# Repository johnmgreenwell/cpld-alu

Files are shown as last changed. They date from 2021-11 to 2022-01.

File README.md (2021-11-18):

# CPLD ALU Test Project

MAX II CPLD custom ALU with microcontroller interface

## Overview

This test project comprises a custom 8-bit Arithmetic Logic Unit (ALU) written in Verilog and uploaded to an Altera [MAX II EPM240T100C5](https://www.digikey.com/en/products/detail/intel/EPM240T100C5/703853) Complex Programmable Logic Device (CPLD), which is interfaced with a PJRC [Teensy 4.0](https://www.pjrc.com/store/teensy40.html) microcontroller for data exchange and display.

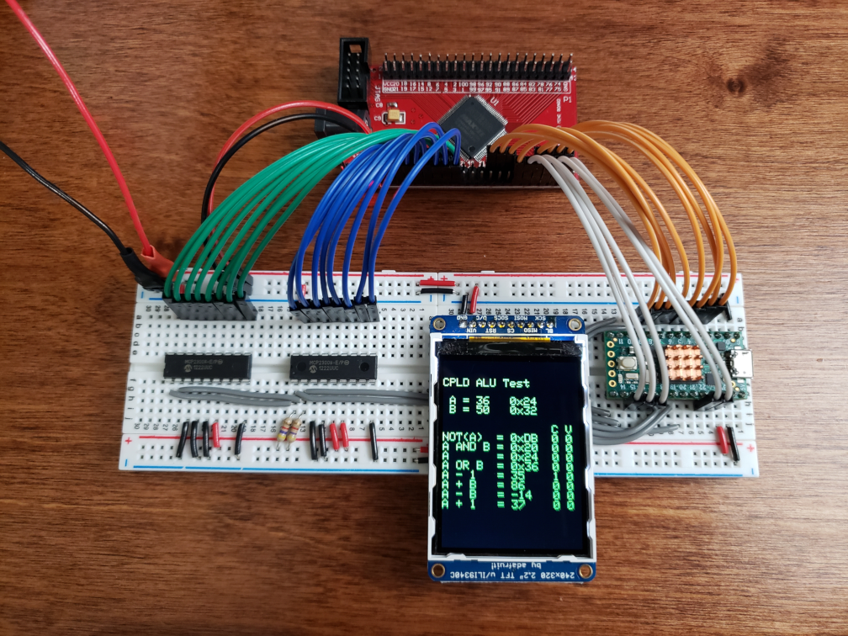
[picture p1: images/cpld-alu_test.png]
Example Breadboard


Inputs A and B are delivered to the ALU from the microcontroller via two Microchip [MCP23008 IO Expander](https://www.digikey.com/en/products/detail/microchip-technology/MCP23008-E-P/735951) chips, while the result F and the ALU control lines are connected to the microcontroller directly. Each of the eight control states are cycled for arbitrary inputs A and B, and the results are displayed using an Adafruit [ILI9340 TFT-LCD](https://www.adafruit.com/product/1480) board.

## Usage

The custom ALU may be instantiated as a single generic unit whose bus widths are determined soley by its assigned parameter N, using the Verilog design file [alun.v](src/cpld/alun.v) (and its dependencies). The design format is fully structural, in order to implement the ALU as a very specific succession of logic gates.

```v
module cpld_alu_top
#(
    parameter N = 8
)
(
    input  m,
    input  [1:0] s,
    input  [N-1:0] a,
    input  [N-1:0] b,
    output [N-1:0] f,
    output v,
    output c
);

alun #(N) uut (
    .m(m),
    .s(s),
    .a(a),
    .b(b),
    .f(f),
    .v(v),
    .c(c)
);

endmodule
```

The core test cycle performed by the microcontroller consists of assigning A, B, and the control lines as outputs to the ALU, and querying the results F, Co, and Ov as inputs. Two custom libraries, [mcp23x08.h](src/controller/src/mcp23x08.h) and [virtualport.h](src/controller/src/virtualport.h) are used to handle this IO, and the LCD is operated using the [Adafruit_ILI9340](https://github.com/adafruit/Adafruit_ILI9340) external library. All eight control states are tested in this cycle for any given inputs A and B.

```cpp
// Issue each control command 0-7 and print results
for (int8_t i=0; i<8; i++) {
    control.write(i);
    lcd.print(op_str[i]);
    if (i < 4) // Print in hex for logical
        lcd.printf(" = 0x%0*X  ", 2, port_F.read());
    else       // Print in dec for arithmetic
        lcd.printf(" = %-*i  ", 4, (int8_t)port_F.read());
    lcd.printf("%i %i\n",digitalRead(CO_PIN), digitalRead(OV_PIN));
}
```

## Schematic

The block diagram schematic for the ALU is included as drawn in Cadence Virtuoso software.

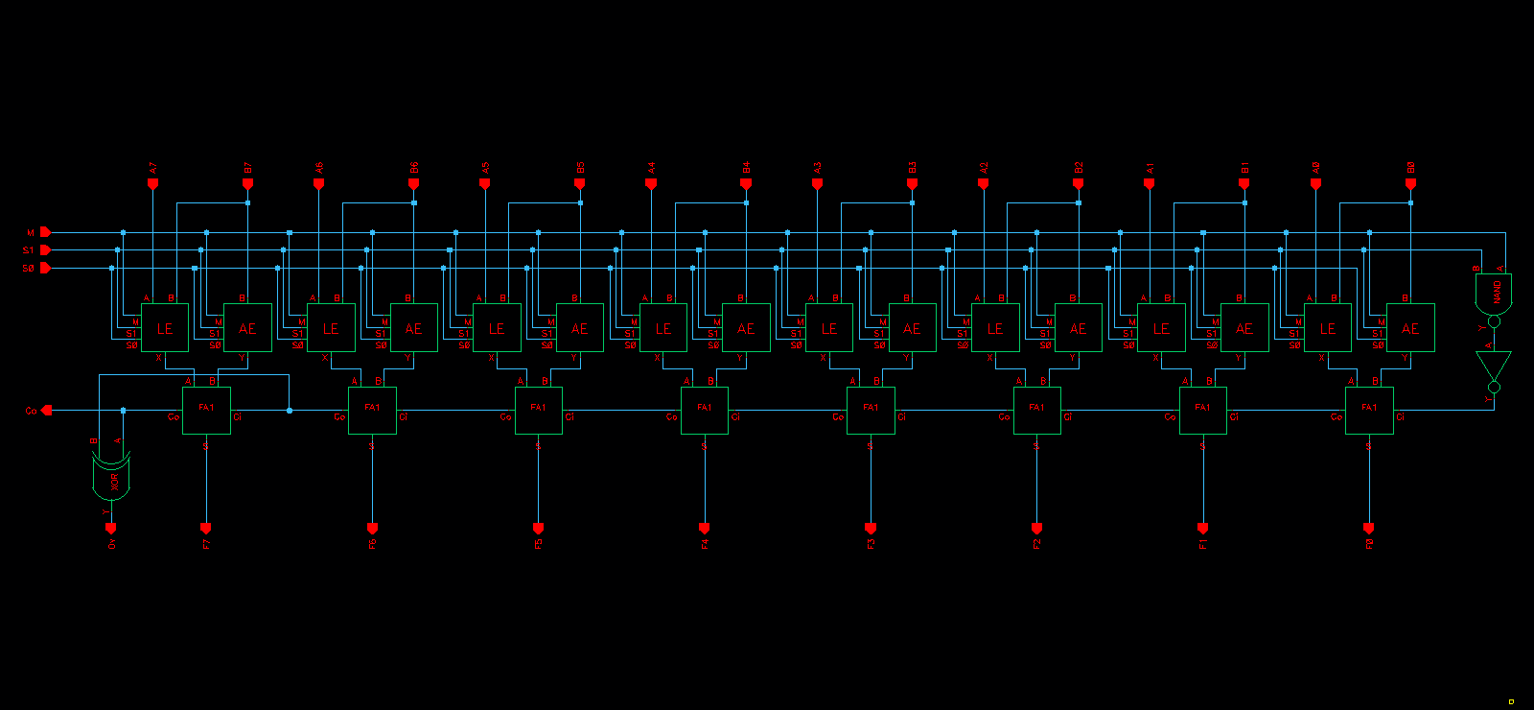
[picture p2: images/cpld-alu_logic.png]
ALU Design FLow


The overall schematic for the test setup, along with its associated CAD files are included as composed in KiCad 5.

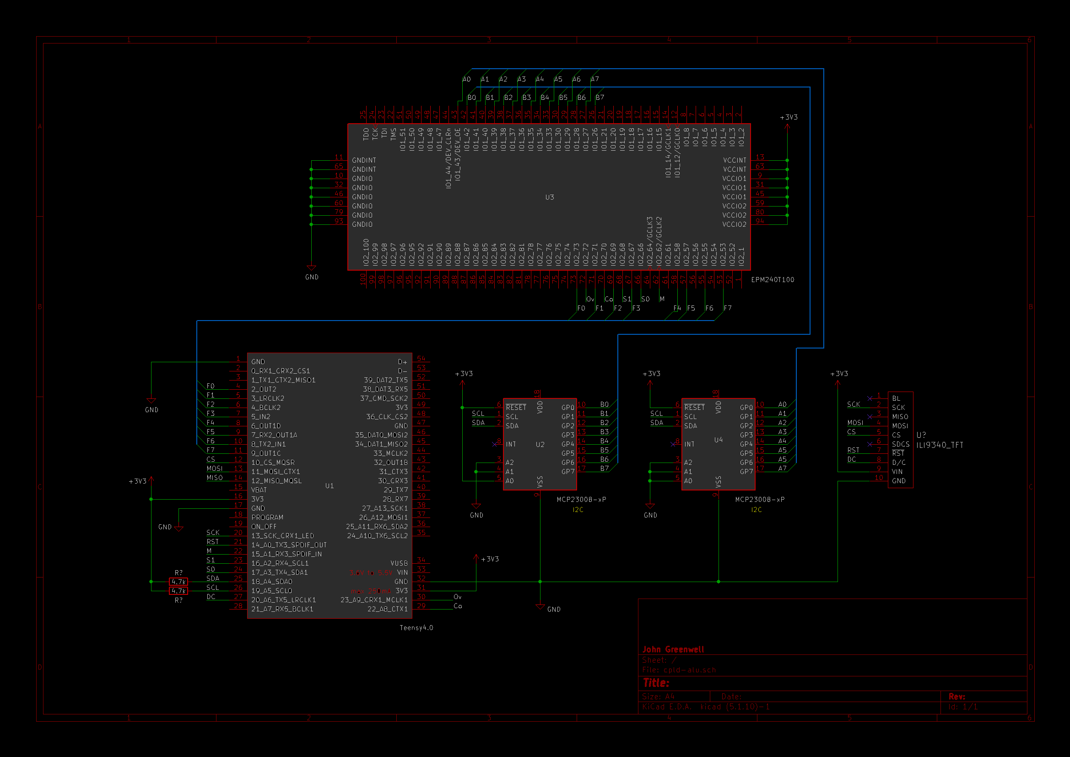
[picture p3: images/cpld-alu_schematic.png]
Test Setup Schematic


## License

MIT © 2021 John Greenwell

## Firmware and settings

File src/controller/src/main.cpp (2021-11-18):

//----------------------------------------------------------------------------
// Name        : main.cpp
// Purpose     : CPLD-ALU Project Controller Main
// Description : 
//               This project is an exercise in microcontroller interface with
//               an 8-bit ALU instantiated on a CPLD. The ILI9340 TFT LCD is
//               used to display the exchange with the ALU.
//
//               The instruction set for the ALU is as follows:
//
//               M,S1,S0  |  Output F
//               ---------|----------------
//                0 0 0   |  complement(A)
//                0 0 1   |  A AND B
//                0 1 0   |  identity(A)
//                0 1 1   |  A OR B
//                1 0 0   |  decrement(A)
//                1 0 1   |  A + B
//                1 1 0   |  A - B
//                1 1 1   |  increment(A)
//
// Platform    : Teensy 4.0
// Framework   : Arduino
// Language    : C++
// Copyright   : MIT License 2021, John Greenwell
// Requires    : External Libraries : Adafruit_ILI9340.h (and dependencies)
//               Custom Libraries   : mcp23x08.h
//                                    virtualport.h
//----------------------------------------------------------------------------

#include <Arduino.h>
#include <Wire.h>
#include <SPI.h>
#include <Adafruit_GFX.h>
#include "Adafruit_ILI9340.h"
#include "mcp23x08.h"
#include "virtualport.h"

// CONFIG: Pin Assignment
const uint8_t PORT_F_PINS[8] = {2, 3, 4, 5, 6, 7, 8, 9};
const uint8_t CONTROL_PINS[3] = {17, 16, 15};
const uint8_t OV_PIN      = 23;
const uint8_t CO_PIN      = 22;
const uint8_t LCD_RST_PIN = 14;
const uint8_t LCD_DC_PIN  = 20;
const uint8_t LCD_CS_PIN  = 10;

// CONFIG: Initial Values
const int8_t A_START = 0;
const int8_t B_START = 50;

// Peripheral Objects
Adafruit_ILI9340 lcd = Adafruit_ILI9340(LCD_CS_PIN, LCD_DC_PIN, LCD_RST_PIN);
PeripheralIO::MCP23X08 port_A;
PeripheralIO::MCP23X08 port_B;
PeripheralIO::VirtualPort port_F;
PeripheralIO::VirtualPort control;

// Main program
void setup(void) {
    // Setup all IO
    port_A.begin(0x00);
    port_B.begin(0x01);
    port_F.begin(PORT_F_PINS);
    control.begin(CONTROL_PINS, 3);
    port_A.portMode(OUTPUT);
    port_B.portMode(OUTPUT);
    port_F.portMode(INPUT);
    control.portMode(OUTPUT);
    pinMode(OV_PIN, INPUT);
    pinMode(CO_PIN, INPUT);
    control.write(0x00);
    port_A.write(A_START);
    port_B.write(B_START);

    // Setup LCD
    lcd.begin();
    lcd.setRotation(2);
    lcd.fillScreen(ILI9340_BLACK);
    lcd.setTextColor(ILI9340_GREEN, ILI9340_BLACK);
    lcd.setTextSize(2);
}

// Main loop
void loop() {
    static const String op_str[8] =
        {"NOT(A) ", "A AND B", "A      ", "A OR B ",
         "A - 1  ", "A + B  ", "A - B  ", "A + 1  "};
    // Properly format display
    lcd.setCursor(0, 0);
    lcd.print("\n\nCPLD ALU Test\n\n");
    lcd.printf(" A = %-*i ", 4, (int8_t)port_A.read());
    lcd.printf("0x%0*X\n", 2, port_A.read());
    lcd.printf(" B = %-*i ", 4, (int8_t)port_B.read());
    lcd.printf("0x%0*X", 2, port_B.read());
    lcd.setCursor(192, 112);
    lcd.print("C V\n");
    // Issue each control command 0-7 and print results
    for (int8_t i=0; i<8; i++) {
        control.write(i);
        lcd.print(op_str[i]);
        if (i < 4) // Print in hex for logical
            lcd.printf(" = 0x%0*X  ", 2, port_F.read());
        else       // Print in dec for arithmetic
            lcd.printf(" = %-*i  ", 4, (int8_t)port_F.read());
        lcd.printf("%i %i\n",digitalRead(CO_PIN), digitalRead(OV_PIN));
    }
    // Increment A each loop
    port_A.write(port_A.read()+1);
    delay(2000);
}

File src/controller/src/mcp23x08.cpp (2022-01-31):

//----------------------------------------------------------------------------
// Name        : mcp23x08.cpp
// Purpose     : MCP23X08 IO-Expander Chip Controller Class
// Description : This source file accompanies header file mcp23x08.h
// Platform    : Multiple
// Framework   : Arduino
// Language    : C++
// Copyright   : MIT License 2021, John Greenwell
//----------------------------------------------------------------------------

#include <Arduino.h>
#include <Wire.h>
#include <SPI.h>
#include "mcp23x08.h"

namespace PeripheralIO {

MCP23X08::MCP23X08()
: _wire(nullptr),
  _spi(nullptr),
  _address(0),
  _cs(0)
{ }

/*!
    @brief Initialize MCP23X08 using I2C
    @param address 3 LSB matching device external biasing
    @param wire I2C object connected to the device
*/
void MCP23X08::begin(uint8_t address, TwoWire& wire) {
    _address = MCP23X08_ADDR | (address & 0x07);
    _wire = &wire;
    _mcpWrite = &PeripheralIO::MCP23X08::i2cWrite;
    _mcpRead = &PeripheralIO::MCP23X08::i2cRead;
}

/*!
    @brief Initialize MCP23X08 using hardware SPI
    @param address 2 LSB matching device external biasing
    @param cs_pin CS pin number
    @param spi SPI object connected to the device
*/
void MCP23X08::begin(uint8_t address, uint8_t cs_pin, SPIClass& spi) {
    _address = (MCP23X08_ADDR << 1) | ((address & 0x03) << 1);
    _cs = cs_pin;
    _spi = &spi;
    _mcpWrite = &PeripheralIO::MCP23X08::spiWrite;
    _mcpRead = &PeripheralIO::MCP23X08::spiRead;
    ::pinMode(_cs, OUTPUT);
    ::digitalWrite(_cs, HIGH);
}

/*!
    @brief Set mode for specific pin
    @param pin Pin to change IO mode
    @param mode IO Mode (i.e. OUTPUT, INPUT, INPUT_PULLUP)
    @return Boolean true for completion, false for bad input
*/
bool MCP23X08::pinMode(uint8_t pin, uint8_t mode) const {
    uint8_t data = 0;
    if (pin > 7) return false;
    data = read(MCP23X08_IODIR);
    if (mode == INPUT) { 
        data |= (1 << pin);
    } else if (mode == OUTPUT) {
        data &= ~(1 << pin);
    } else if (mode == INPUT_PULLUP){
        data |= (1 << pin);
        write(MCP23X08_GPPU, read(MCP23X08_GPPU) | (1 << pin));
    } else {
        return false;
    }
    write(MCP23X08_IODIR, data);
    return true;
}

/*!
    @brief Assign same pin mode to entire GPIO port
    @param mode IO Mode (i.e. OUTPUT, INPUT, INPUT_PULLUP)
*/
void MCP23X08::portMode(uint8_t mode) const {
    if (mode == INPUT) { 
        write(MCP23X08_IODIR, 0xFF);
    } else if (mode == OUTPUT) {
        write(MCP23X08_IODIR, 0x00);
    } else if (mode == INPUT_PULLUP){
        write(MCP23X08_GPPU, 0xFF);
        write(MCP23X08_IODIR, 0xFF);
    }
}

/*!
    @brief Set value for specific pin
    @param pin Pin to set
    @param val Logic level (i.e. HIGH, LOW)
    @result Boolean true for completion, false for bad input
*/
bool MCP23X08::digitalWrite(uint8_t pin, uint8_t val) const {
    uint8_t data = 0;
    if (pin > 7) return false;
    data = read(MCP23X08_GPIO);
    data = (val == HIGH) ? (data | 1 << pin) : (data & ~(1 << pin));
    write(MCP23X08_GPIO, data);
    return true;
}

/*!
    @brief Read value on specific pin
    @param pin Pin to read
    @result Value read
*/
uint8_t MCP23X08::digitalRead(uint8_t pin) const {
    if (pin > 7) return 0x00;
    return ((read(MCP23X08_GPIO) >> pin) & 0x01);
}

/*!
    @brief Write to entire GPIO port
    @param val Value to write to GPIO port
*/
void MCP23X08::write(uint8_t val) const {
    write(MCP23X08_OLAT, val);
}

/*!
    @brief Write value to specific register
    @param reg Register to access
    @param val Value to write to register
*/
void MCP23X08::write(uint8_t reg, uint8_t val) const {
    (this->*_mcpWrite)(reg, val);
}

/*!
    @brief Read from entire GPIO port
    @return Value read from GPIO port
*/
uint8_t MCP23X08::read() const {
    return read(MCP23X08_GPIO);
}

/*!
    @brief Read value from specific register
    @param reg Register to access
    @return Value read from register
*/
uint8_t MCP23X08::read(uint8_t reg) const {
    return (this->*_mcpRead)(reg);
}

// Private: Hardware SPI Write Function
void MCP23X08::spiWrite(uint8_t reg, uint8_t byte) const {
    ::digitalWrite(_cs, LOW);
    _spi->transfer(_address);
    _spi->transfer(reg);
    _spi->transfer(byte);
    ::digitalWrite(_cs, HIGH);
}

// Private: Hardware SPI Read Function
uint8_t MCP23X08::spiRead(uint8_t reg) const {
    uint8_t data = 0;
    ::digitalWrite(_cs, LOW);
    _spi->transfer(_address | 0x01);
    _spi->transfer(reg);
    data = _spi->transfer(0);
    ::digitalWrite(_cs, HIGH);
    return data;
}

// Private: Hardware I2C Write Function
void MCP23X08::i2cWrite(uint8_t reg, uint8_t byte) const {
    _wire->beginTransmission(_address);
    _wire->write(reg);
    _wire->write(byte);
    _wire->endTransmission();
}

// Private: Hardware I2C Read Function
uint8_t MCP23X08::i2cRead(uint8_t reg) const {
    uint8_t data = 0;
    _wire->beginTransmission(_address);
    _wire->write(reg);
    _wire->endTransmission(0);
    _wire->requestFrom(_address, (uint8_t)1);
    if (_wire->available()) data = Wire.read();
    _wire->endTransmission();
    return data;
}

// Base Address and Register Defines
const uint8_t MCP23X08_ADDR    = 0x20; // 7-bit addr
const uint8_t MCP23X08_IODIR   = 0x00;
const uint8_t MCP23X08_IPOL    = 0x01;
const uint8_t MCP23X08_GPINTEN = 0x02;
const uint8_t MCP23X08_DEFVAL  = 0x03;
const uint8_t MCP23X08_INTCON  = 0x04;
const uint8_t MCP23X08_IOCON   = 0x05;
const uint8_t MCP23X08_GPPU    = 0x06;
const uint8_t MCP23X08_INTF    = 0x07;
const uint8_t MCP23X08_INTCAP  = 0x08;
const uint8_t MCP23X08_GPIO    = 0x09;
const uint8_t MCP23X08_OLAT    = 0x0A;

}

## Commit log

2021-11-18 Minor edits
    Schematic - corrected pin labels on one of the IO expander chips
    [cpld-alu.sch]
2023-12-22 Update kicad schematic files to support kicad 7
    [cpld-alu.kicad_sch]
